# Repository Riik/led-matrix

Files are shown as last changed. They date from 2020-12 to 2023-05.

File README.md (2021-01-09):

# rpi-led-matrix
Python / C control for a LED matrix

# Goal
Create the software for a hardware project which can drive a LED matrix with a extendable number of rows and columns

# Hardware
To drive the rows, the MIC2981 driver IC is used. It can source up to 500mA per pin, which mean 25 columns @ 20mA / column.
To sink the columns, the TPIC6C595 is used. I needs to be able to sink one column (20mA) per pin, so for an 8 bit shift register the total IC must be able to sink 8*20mA. The TPIC6C595 is able to sink up to 100mA per pin.
The rows should multiplexed, i.e. they should not be one at the same time.

# Software
Suitable candidates:
  - PIGpio Python library using DMA control http://abyz.me.uk/rpi/pigpio/
  - Directly talking to SPI hardware in C using IOCTL

# Notes to selfs
  - If multiple rows are active, current is split / LEDS are in parallel with respect to the sinking column.
  - We probably need a resistor per sink / column

# On the subject of the LED matrix 3D model
For this model, we use two programs: OpenSCAD and FreeCAD. OpenSCAD is used to program the model. To make the model readable for KiCad:
1. Open FreeCAD
2. Select View->Workbench->OpenSCAD
3. Open the *.scad file (File->Open)
4. In Combo View->Model->Labels & Attributes->2088BS select union
5. Go to File->Export
6. Export the model as a STEP with colors (*.step *.stp)

# Selected components
 - 100 Ohm 1206 [3216 Metric]: Vishay CRCW1206100RFKEA (https://nl.farnell.com/vishay/crcw1206100rfkea/res-100r-1-0-25w-1206-thick-film/dp/1469977,
 - 10 kOhm 1206 [3216 Metric]: Vishay CRCW120610K0FKEA (https://nl.farnell.com/vishay/crcw120610k0fkea/res-10k-1-0-25w-1206-thick-film/dp/1469970RL,
 - 100 nF (0.1 uF) 1206 [3216 Metric] capacitor: Vishay VJ1206Y104KXQCW1BC (https://nl.farnell.com/vishay/vj1206y104kxqcw1bc/cap-0-1-f-10v-10-x7r-1206/dp/2896644RL,
 - Pin header male: https://nl.farnell.com/multicomp/mc34753/header-1-row-r-angle-8way/dp/1593431?ost=mc34753,
 - Pin header female: https://nl.farnell.com/samtec/ssw-108-02-g-s-ra/receptacle-2-54mm-r-a-single-8way/dp/1668368,

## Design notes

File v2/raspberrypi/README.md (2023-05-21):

This project is able to drive the v2 LED matrix from a raspberry pi 3/4.

# General info
## Configuring the raspberry pi
### SPI
We can configure the SPI very bare-bones, we do not need the MISO line and 1 cs is enough.
Therefore, add the following to `/boot/config`:
```
dtoverlay=spi0-1cs,no_miso
```
If you want to be able to use the spi device as a non-root user, you should create an `spiuser` group:
```
groupadd spiuser
```
Next, create the file `/etc/udev/rules.d/50-spi.rules` with the following content:
```
SUBSYSTEM=="spidev", GROUP="spiuser", MODE="0660"
```
And add your own user to the `spiuser` group:
```
usermod -a -G spiuser <user>
```
You need to log out and log in for the usermod command to take effect.
## Connection
The silkscreen for the male side contains an error, the silkscreen for the female side is correct. You want to connect the female side to the Raspberry Pi. Following [This image](https://www.raspberrypi.com/documentation/computers/images/GPIO-Pinout-Diagram-2.png) we get:
- `Vcc` <--> `5v`
- `GND` <--> `GND`
- `Load` <--> `24` (CE0)
- `CLK` <--> `23` (SCLK)
- `D_in` <--> `19` (MOSI)
- `D_fwd` `N.C.` (d_fwd needs to be connected to another LED matrix)

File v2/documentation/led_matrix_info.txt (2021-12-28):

Led Matrix 8x8 with 3.75 mm pitch between the LED's. LED color is red.

Specifications:

    16 pins connections
    Dimensions: 37.6x37.6mm
    Input voltage: 1.96-2.0 V
    Current:  20 mA

Pinout is indicated in the product images.

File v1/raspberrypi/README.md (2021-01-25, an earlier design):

# On the subject of permissions
To use this software, you need interaction with both gpio and spi. The default permissions for the relevant
devices is root-only, so that you would need to use sudo to run. This is not fun. To fix this, one can create two files:
`/etc/udev/rules.d/50-spi.rules`
```
SUBSYSTEM=="spidev", GROUP="spiuser", MODE="0660"
```
`/etc/udev/rules.d/90-gpio.rules`
```
SUBSYSTEM=="gpio", GROUP="gpiouser", MODE="0660"
```
After udev has been reloaded, the GPIO and SPI devices will be available for users in the groups gpiouser and spiuser.
So add yourself to these groups.

# On the subject of GPIOD
GPIOD is used to control pins directly. The disadvantage of this approach is that, in order to cross-compile, you need the library.
One way to achieve this is to download [the source](https://git.kernel.org/pub/scm/libs/libgpiod/libgpiod.git), run `./autogen.sh --enable-tools=no --prefix=/tmp/libgpiod --host=arm-linux-gnueabihf`, then run `make install` and finally copy `/tmp/libgpiod` to here.

# On the subject of SPI
To control the LED matrix, we use an SPI to transmit data across.
For our purposes, SPI0 is chosen. This means that SPI0 should be enabled, so that `dtoverlay=spi0-1cs` must be added to `/boot/config.txt`.
See also the [raspberry pi documentation](https://www.raspberrypi.org/documentation/hardware/raspberrypi/spi/README.md).

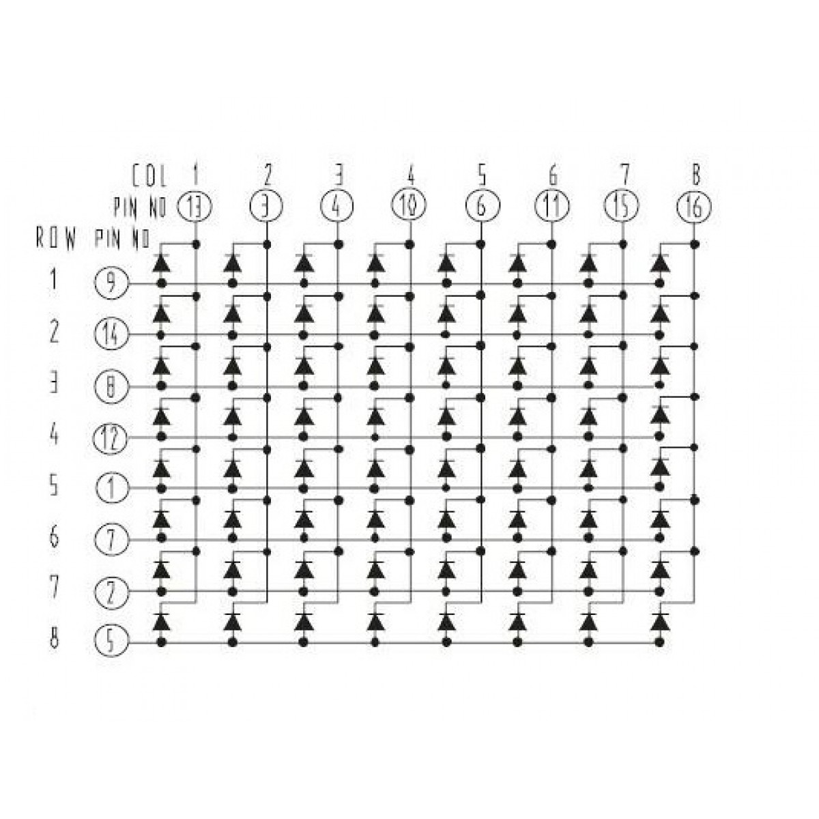
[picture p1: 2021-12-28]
v2/documentation/led_matrix_pinout.jpg

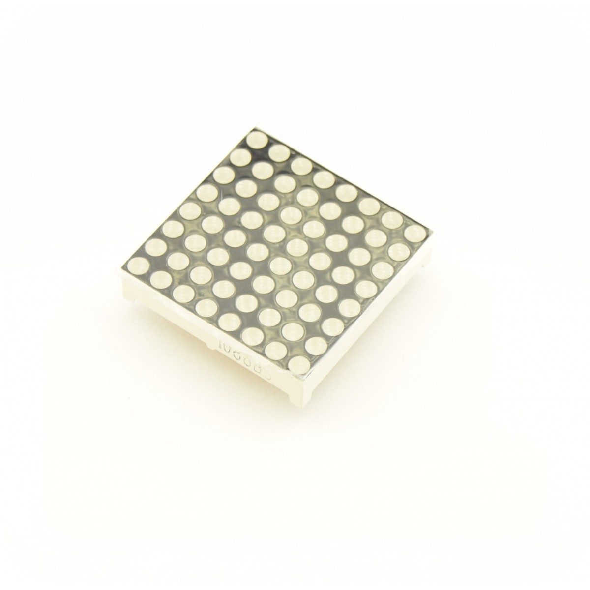
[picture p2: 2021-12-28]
v2/documentation/led_matrix_photo.JPG

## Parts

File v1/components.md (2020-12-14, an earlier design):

CD74HCT4051E, analog 1:8 mux/demux
TPIC6C595N, 8 bit shift register
MIC2981, MIC2981

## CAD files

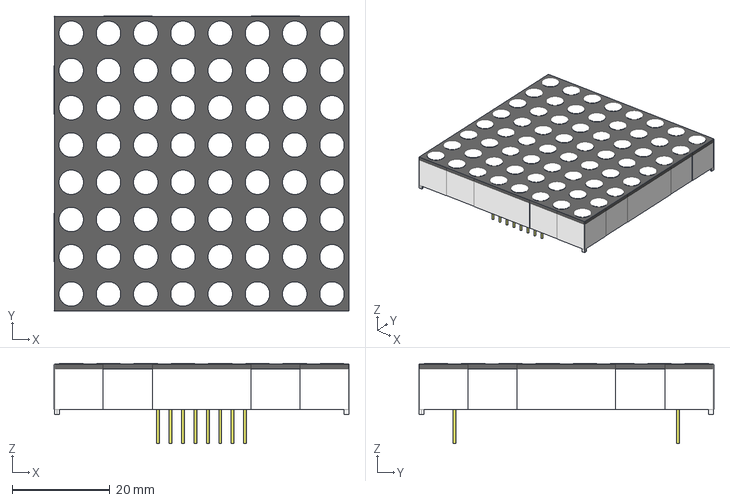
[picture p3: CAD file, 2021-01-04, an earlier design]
v1/kicad/led-matrix/openscad_3d/2088BS.step
60.3 x 60.3 x 16.4 mm

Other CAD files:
v1/kicad/led-matrix/openscad_3d/2088BS.scad

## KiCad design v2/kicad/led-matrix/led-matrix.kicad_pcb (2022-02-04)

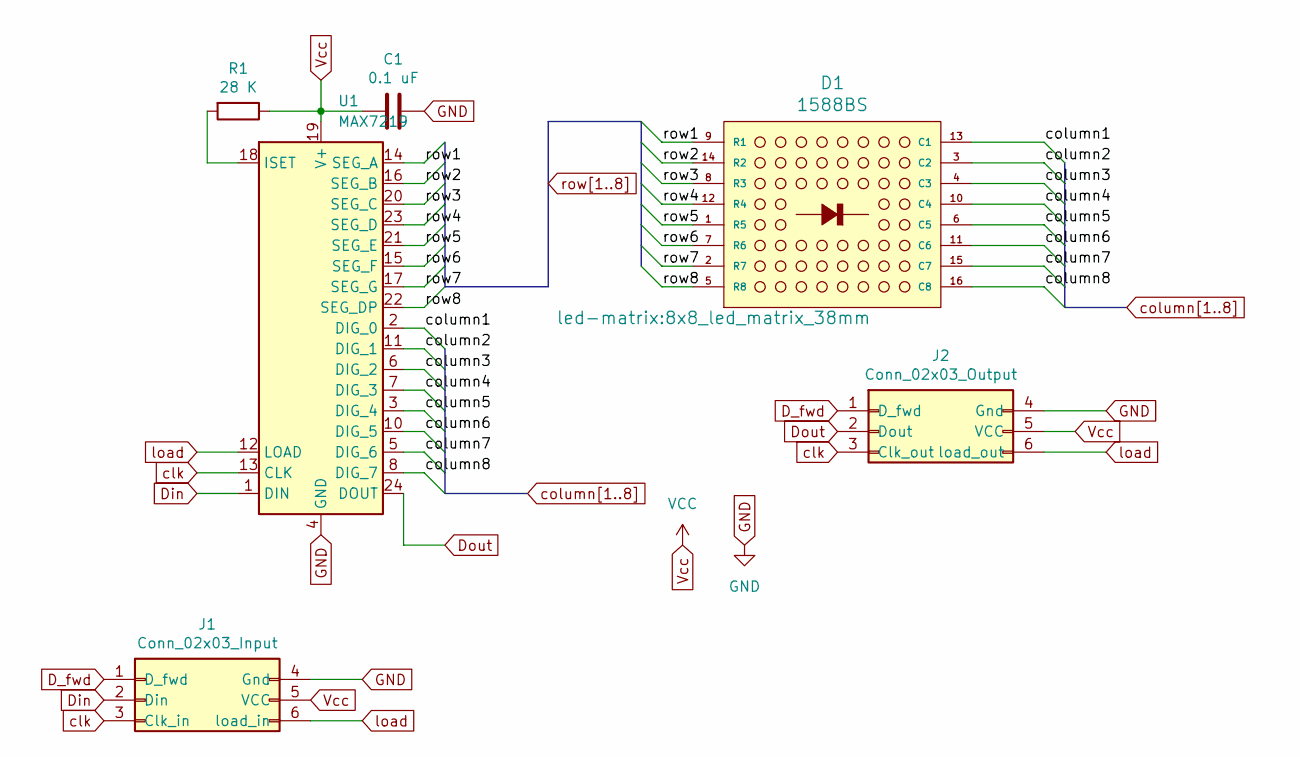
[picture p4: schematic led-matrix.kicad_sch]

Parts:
C1: 0.1 uF; C_1206_3216Metric_Pad1.33x1.80mm_HandSolder
D1: 1588BS; 8x8_led_matrix_38mm
J1: Conn_02x03_Input; PinSocket_2x03_P2.54mm_Horizontal
J2: Conn_02x03_Output; PinHeader_2x03_P2.54mm_Horizontal
R1: 28 K; R_1206_3216Metric_Pad1.30x1.75mm_HandSolder
U1: MAX7219; HandSolder.SOIC-24W_7.5x15.4mm_P1.27mm

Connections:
D_fwd: J1.1 (D_fwd), J2.1 (D_fwd)
Din: J1.2 (Din), U1.1 (DIN)
Dout: J2.2 (Dout), U1.24 (DOUT)
GND: C1.1, J1.4 (Gnd), J2.4 (Gnd), U1.4 (GND), U1.9 (GND)
unnamed: R1.2, U1.18 (ISET)
Vcc: C1.2, J1.5 (VCC), J2.5 (VCC), R1.1, U1.19 (V+)
clk: J1.3 (Clk_in), J2.3 (Clk_out), U1.13 (CLK)
column1: D1.13 (C1), U1.2 (DIG_0)
column2: D1.3 (C2), U1.11 (DIG_1)
column3: D1.4 (C3), U1.6 (DIG_2)
column4: D1.10 (C4), U1.7 (DIG_3)
column5: D1.6 (C5), U1.3 (DIG_4)
column6: D1.11 (C6), U1.10 (DIG_5)
column7: D1.15 (C7), U1.5 (DIG_6)
column8: D1.16 (C8), U1.8 (DIG_7)
load: J1.6 (load_in), J2.6 (load_out), U1.12 (LOAD)
row1: D1.9 (R1), U1.14 (SEG_A)
row2: D1.14 (R2), U1.16 (SEG_B)
row3: D1.8 (R3), U1.20 (SEG_C)
row4: D1.12 (R4), U1.23 (SEG_D)
row5: D1.1 (R5), U1.21 (SEG_E)
row6: D1.7 (R6), U1.15 (SEG_F)
row7: D1.2 (R7), U1.17 (SEG_G)
row8: D1.5 (R8), U1.22 (SEG_DP)

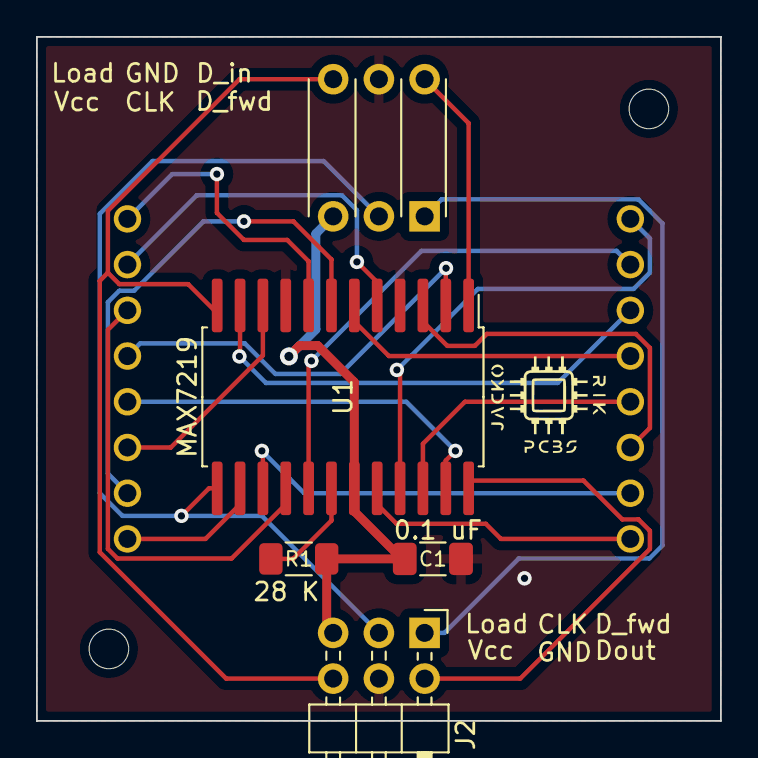
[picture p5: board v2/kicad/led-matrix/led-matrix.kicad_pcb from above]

Board: 2 copper layers, 38.0 x 38.0 mm, 6 parts (1 on the bottom side), 24 nets.

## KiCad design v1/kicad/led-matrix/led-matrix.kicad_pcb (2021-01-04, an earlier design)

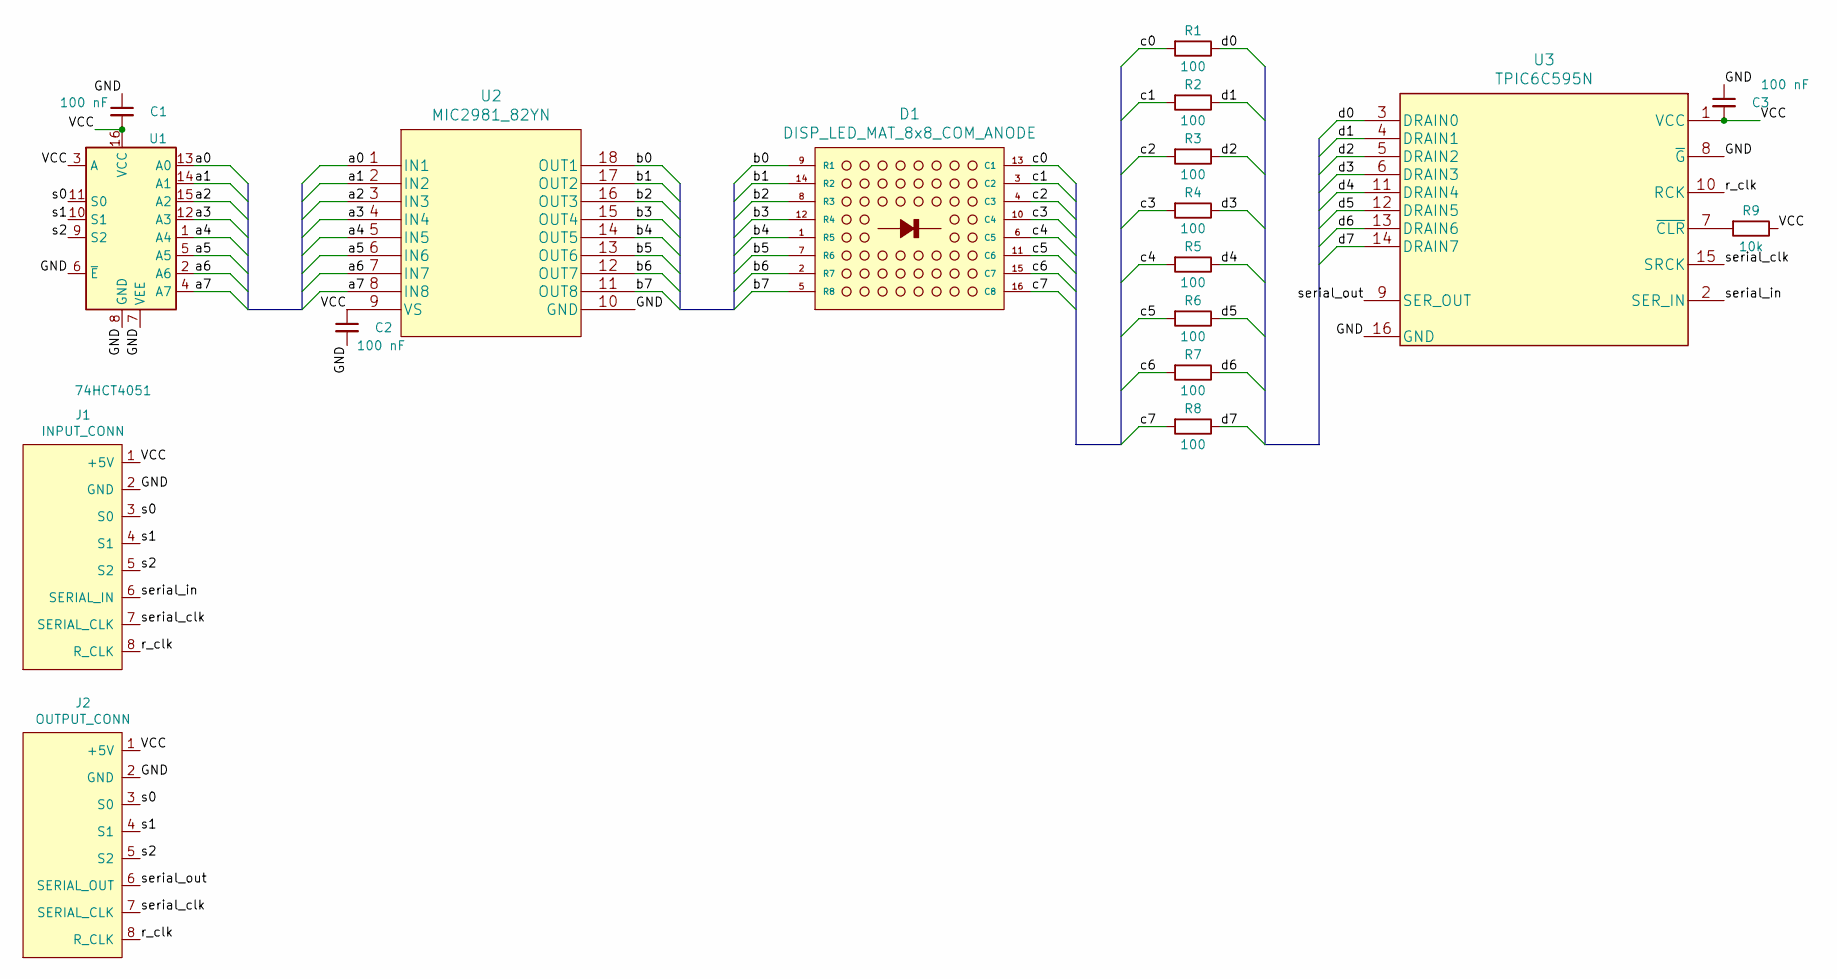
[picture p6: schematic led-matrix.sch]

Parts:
C1, C2, C3: 100 nF; C_1206_3216Metric_Pad1.33x1.80mm_HandSolder
D1: DISP_LED_MAT_8x8_COM_ANODE; LED_8x8_7.62MM_60.2x60.2MM
J1: INPUT_CONN; PinSocket_1x08_P2.54mm_Horizontal
J2: OUTPUT_CONN; PinHeader_1x08_P2.54mm_Horizontal
R1, R2, R3, R4, R5, R6, R7, R8: 100; R_1206_3216Metric_Pad1.30x1.75mm_HandSolder
R9: 10k; R_1206_3216Metric_Pad1.30x1.75mm_HandSolder
U1: 74HCT4051; DIP-16_W7.62mm
U2: MIC2981_82YN; DIP-18_W7.62mm
U3: TPIC6C595N; DIP-16_W7.62mm

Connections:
/GND: C1.1, C2.2, C3.1, J1.2 (GND), J2.2 (GND), U1.6 (~E), U1.7 (VEE), U1.8 (GND), U2.10 (GND), U3.8 (~G), U3.16 (GND)
/VCC: C1.2, C2.1, C3.2, J1.1 (+5V), J2.1 (+5V), R9.1, U1.3 (A), U1.16 (VCC), U2.9 (VS), U3.1 (VCC)
/a0: U1.13 (A0), U2.1 (IN1)
/a1: U1.14 (A1), U2.2 (IN2)
/a2: U1.15 (A2), U2.3 (IN3)
/a3: U1.12 (A3), U2.4 (IN4)
/a4: U1.1 (A4), U2.5 (IN5)
/a5: U1.5 (A5), U2.6 (IN6)
/a6: U1.2 (A6), U2.7 (IN7)
/a7: U1.4 (A7), U2.8 (IN8)
/b0: D1.9 (R1), U2.18 (OUT1)
/b1: D1.14 (R2), U2.17 (OUT2)
/b2: D1.8 (R3), U2.16 (OUT3)
/b3: D1.12 (R4), U2.15 (OUT4)
/b4: D1.1 (R5), U2.14 (OUT5)
/b5: D1.7 (R6), U2.13 (OUT6)
/b6: D1.2 (R7), U2.12 (OUT7)
/b7: D1.5 (R8), U2.11 (OUT8)
/c0: D1.13 (C1), R1.2
/c1: D1.3 (C2), R2.2
/c2: D1.4 (C3), R3.2
/c3: D1.10 (C4), R4.2
/c4: D1.6 (C5), R5.2
/c5: D1.11 (C6), R6.2
/c6: D1.15 (C7), R7.2
/c7: D1.16 (C8), R8.2
/d0: R1.1, U3.3 (DRAIN0)
/d1: R2.1, U3.4 (DRAIN1)
/d2: R3.1, U3.5 (DRAIN2)
/d3: R4.1, U3.6 (DRAIN3)
/d4: R5.1, U3.11 (DRAIN4)
/d5: R6.1, U3.12 (DRAIN5)
/d6: R7.1, U3.13 (DRAIN6)
/d7: R8.1, U3.14 (DRAIN7)
/r_clk: J1.8 (R_CLK), J2.8 (R_CLK), U3.10 (RCK)
/s0: J1.3 (S0), J2.3 (S0), U1.11 (S0)
/s1: J1.4 (S1), J2.4 (S1), U1.10 (S1)
/s2: J1.5 (S2), J2.5 (S2), U1.9 (S2)
/serial_clk: J1.7 (SERIAL_CLK), J2.7 (SERIAL_CLK), U3.15 (SRCK)
/serial_in: J1.6 (SERIAL_IN), U3.2 (SER_IN)
/serial_out: J2.6 (SERIAL_OUT), U3.9 (SER_OUT)
unnamed: R9.2, U3.7 (~CLR)

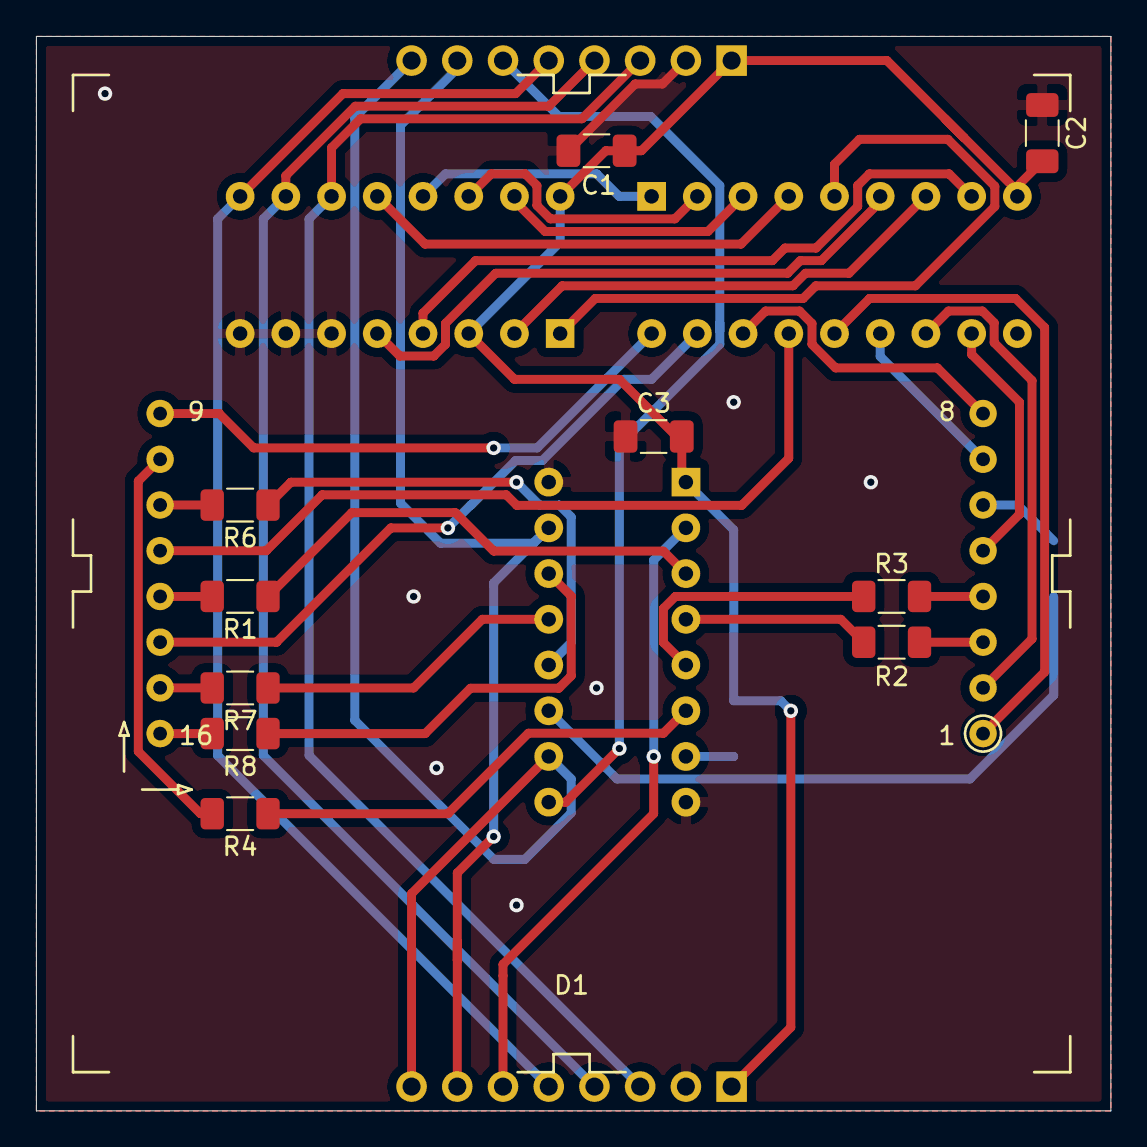
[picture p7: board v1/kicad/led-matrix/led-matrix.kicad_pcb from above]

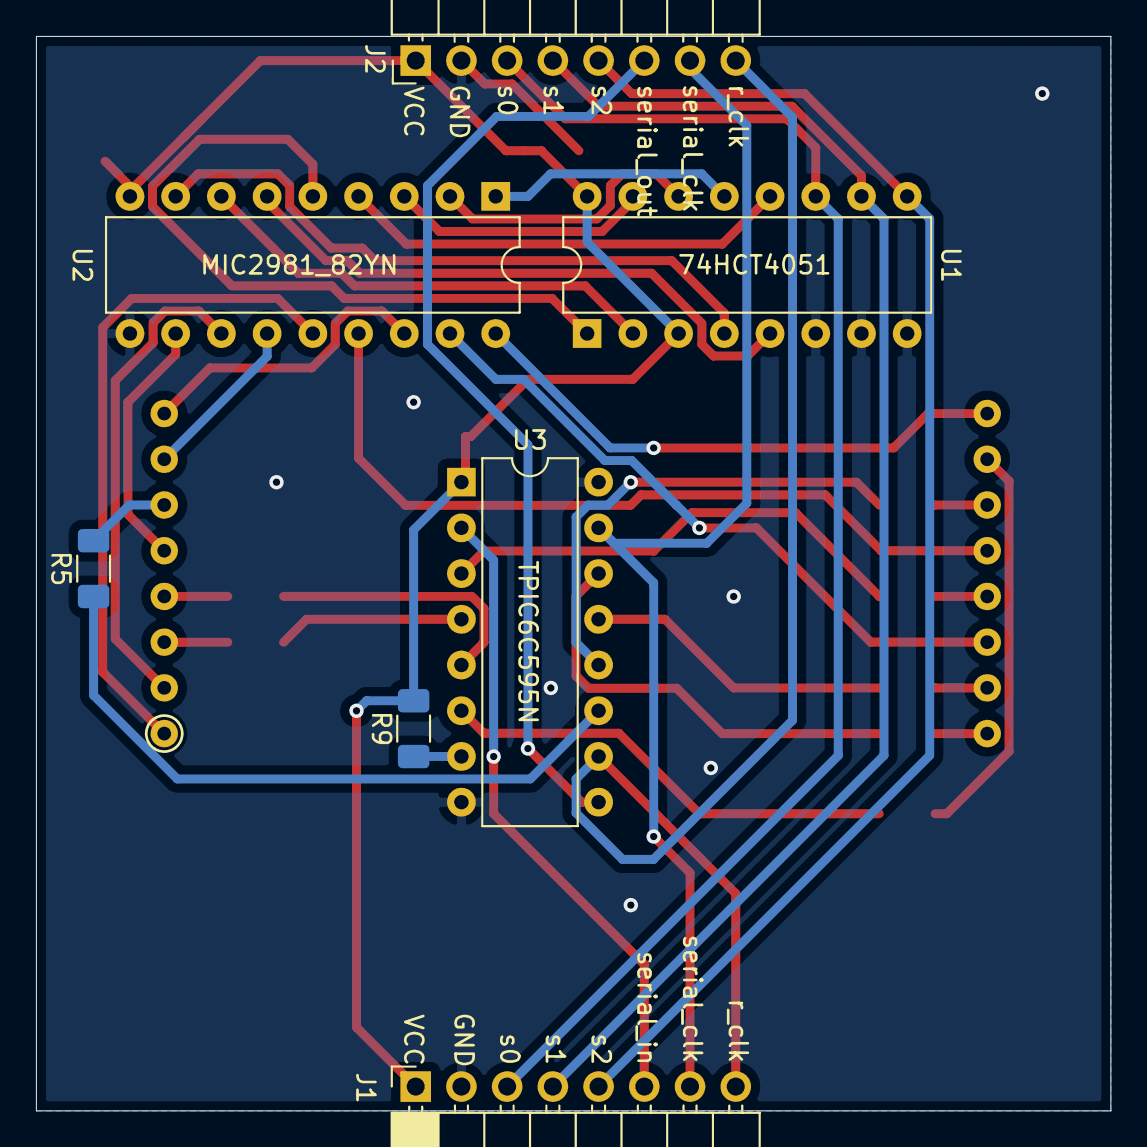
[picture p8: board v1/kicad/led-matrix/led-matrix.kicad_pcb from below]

Board: 2 copper layers, 59.7 x 59.7 mm, 18 parts (7 on the bottom side), 42 nets.

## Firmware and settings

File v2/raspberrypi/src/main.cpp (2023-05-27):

#include <atomic>
#include <csignal>
#include <vector>
#include <chrono>
#include <stdexcept>
#include <iostream>
#include <memory>

#include "matrixScreen.hpp"
#include "matrixDriver.hpp"
#include "matrixDriverSpi.hpp"
#include "matrixDriverNcurses.hpp"
#include "frameLimiter.hpp"
#include "argumentParser.hpp"
#include "textScroller.hpp"
#include "diceGenerator.hpp"

const std::string spidev = "/dev/spidev0.0";
static std::atomic_bool halt = false;

static void sigintHandler(int signum)
{
    halt = true;
}

int main(int argc, char * const argv[]) {
    signal(SIGINT, sigintHandler);

    ParsedArguments pArgs;
    try {
        pArgs = parseArguments(argc, argv);
    } catch (const std::invalid_argument& e) {
        std::cerr << e.what() << std::endl;
        return EXIT_FAILURE;
    }

    MatrixScreen referenceScreen(pArgs.ledMatrixWidth, pArgs.ledMatrixHeight);
    FrameLimiter frameLimiter(pArgs.maxFramesPerSecond);
    std::unique_ptr<MatrixDriver> matrixDriver;
#if !defined(__APPLE__)
    if (pArgs.matrixDriver == SelectedMatrixDriver::spi) {
        matrixDriver = std::make_unique<MatrixDriverSpi>(spidev, referenceScreen, pArgs.brightness);
    } else {
#endif //!defined(__APPLE__)
        matrixDriver = std::make_unique<MatrixDriverNcurses>();
#if !defined(__APPLE__)
    }
#endif //!defined(__APPLE__)
    std::unique_ptr<SubProgram> subProgram;
    if (pArgs.subProgram == SelectedSubProgram::diceGenerator) {
        subProgram = std::make_unique<DiceGenerator>(referenceScreen, pArgs);
    } else {
        subProgram = std::make_unique<TextScroller>(referenceScreen, pArgs);
    }
    while(!halt) {
        matrixDriver->setScreen(subProgram->getScreen());
        frameLimiter.waitForNextFrame();
    }
    return EXIT_SUCCESS;
}

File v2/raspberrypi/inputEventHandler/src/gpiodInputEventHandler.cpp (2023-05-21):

#if !defined(__APPLE__)
#include <iostream>
#include <system_error>
#include <cassert>

#include "gpiodInputEventHandler.hpp"

#include <sys/time.h>

#define BUTTON_PIN 5


GpiodInputEventHandler::GpiodInputEventHandler()
{
    this->chip = gpiod_chip_open("/dev/gpiochip0");
    if(!this->chip) perror("gpiod_chip_open");

    errno = 0;
    this->line = gpiod_chip_get_line(chip, BUTTON_PIN);
    int ret = gpiod_line_request_input(line, "");
    assert(ret == 0);
    int wiee = gpiod_line_set_flags(this->line, GPIOD_LINE_REQUEST_FLAG_BIAS_DISABLE);
    assert(wiee == 0);
    gpiod_line_release(this->line);
    this->line = gpiod_chip_get_line(chip, BUTTON_PIN);

    int err = gpiod_line_request_rising_edge_events(this->line, "rising edge example");
    if(err) perror("gpiod_line_request_bulk_rising_edge_events");
}

GpiodInputEventHandler::~GpiodInputEventHandler(){
    gpiod_line_release(this->line);
    gpiod_chip_close(this->chip);
}

void GpiodInputEventHandler::flushWaitingEvents() {
    gpiod_line_event event;
    while(this->eventWaiting()) {
        gpiod_line_event_read(this->line, &event);
    }
}

bool GpiodInputEventHandler::eventWaiting() {
    static struct timespec timeout = {0};
    int ret = gpiod_line_event_wait(this->line, &timeout);
    if (ret == -1) perror("gpiod_line_event_wait");
    return ret == 1;
}

#endif //!defined(__APPLE)

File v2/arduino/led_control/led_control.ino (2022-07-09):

#include <SPI.h>
#include "font.cpp"
#include <avr/eeprom.h>

#define LOAD  8  // can be changed
#define CLK   13 // fixed by hardware SPI 
#define DATA  11 // fixed by hardware SPI

#define ADDR_INTENSITY  0x0A
#define ADDR_SCAN_LIMIT 0x0B
#define ADDR_SHUTDOWN   0x0C
#define ADDR_TESTMODE   0x0F

#define N_PANELS 8
#define BUFFER_LEN (N_PANELS+1)*8

#define TEXT_BUFF_SIZE 80

#define SPI_SPEED 10000

uint8_t frame_buffer[BUFFER_LEN];
SPISettings spiSettings(SPI_SPEED, MSBFIRST, SPI_MODE0);

char message_receive_buff[TEXT_BUFF_SIZE];
char message_display_buff[TEXT_BUFF_SIZE] = "Hello world!";
uint8_t input_char_count = 0;
uint8_t message_size = 15;
bool string_complete = false; 

void setRegister(uint8_t address, uint8_t value) {    
  digitalWrite(LOAD, LOW);
  for(uint8_t n = 0; n < N_PANELS; n++){
    SPI.transfer(address);
    SPI.transfer(value);
  }
  digitalWrite(LOAD, HIGH);
  delay(1);
}

void serialEvent() {
  if(input_char_count >= TEXT_BUFF_SIZE){
    string_complete = true;
    return;
  }
  while (Serial.available()) {
    input_char_count++;
    char in_char = (char)Serial.read();
    if (in_char == '\n') {
      string_complete = true;
      return;
    }
    message_receive_buff[input_char_count] = in_char;
  }
}

void sendBuffer() {
    for (uint8_t col = 0; col < 8; col++) {
      digitalWrite(LOAD, LOW);
      for(uint8_t n = 0; n < N_PANELS; n++){
        SPI.transfer(col+1);
        SPI.transfer(frame_buffer[col + (N_PANELS-1-n)*8]);
      }
      digitalWrite(LOAD, HIGH);
      delay(1);
    }
}

void moveData(){
  memmove(frame_buffer,frame_buffer+1, BUFFER_LEN-1);
}

void loadData(uint8_t char_idx){
  const uint8_t* offset = font+char_idx*8;
  memcpy_P(frame_buffer, offset, (size_t) BUFFER_LEN);
}

void loadNewCharacter(uint8_t char_idx){
  const uint8_t* offset = font+char_idx*8;
  memcpy_P(frame_buffer+N_PANELS*8, offset, (size_t) 8);
}

void setup() {
  pinMode(LOAD, OUTPUT);
  pinMode(CLK, OUTPUT);
  pinMode(DATA, OUTPUT);

  SPI.begin();
  SPI.beginTransaction(spiSettings);

  setRegister(ADDR_TESTMODE, 0x00);
  setRegister(ADDR_INTENSITY, 0x01);
  setRegister(ADDR_SHUTDOWN, 0x01);
//  setRegister(ADDR_SCAN_LIMIT, 0x07);
  setRegister(ADDR_SCAN_LIMIT, 0x07);
  
  Serial.begin(115200);
  Serial.println("hi");

}

void loop() {
  for(uint8_t i = 0; i < message_size; i++){
    if(string_complete){
      memcpy(message_display_buff, message_receive_buff, TEXT_BUFF_SIZE);
      message_size = input_char_count;
      input_char_count = 0;
      string_complete = false;
      break;
    }
    loadNewCharacter(message_display_buff[i]);   
    for(uint8_t col = 0; col < 8; col++){
      moveData(); 
      sendBuffer();
      delay(35);
    }
    delay(100);
  }

}

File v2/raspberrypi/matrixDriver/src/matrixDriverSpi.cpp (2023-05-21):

#if !defined(__APPLE__)
#include <system_error>
#include <functional>
#include <sstream>
#include <cassert>

#include <fcntl.h>
#include <unistd.h>
#include <sys/ioctl.h>
#include <linux/spi/spidev.h>

#include "matrixDriverSpi.hpp"

MatrixDriverSpi::MatrixDriverSpi(const std::string &spiDevName, MatrixScreen exampleScreen, uint_fast8_t brightness,
        MatrixDriverSpi::PhysicalConnectionLocation physicalConnectionLocation) :
    screen{std::move(exampleScreen)}, matrixCountWidth{exampleScreen.getMatrixCountWidth()},
    matrixCountHeight{exampleScreen.getMatrixCountHeight()},
    physicalConnectionLocation{physicalConnectionLocation}, newDataAvailable{0}
{
    // All spidev stuff will be done c style, since I cant seem to figure out how to do it c++ style.
    this->spifd = open(spiDevName.c_str(), O_RDWR);
    if (this->spifd < 0) {
        throw std::system_error(errno, std::generic_category(), spiDevName);
    }
    assert(brightness <= 15);

    // Now we need to bring the ledmatrices into a default state.
    const std::size_t matrixCount = this->matrixCountWidth * this->matrixCountHeight;
    std::vector<uint8_t> buf(matrixCount*2, 0);
    struct spi_ioc_transfer tr = {0};
    tr.bits_per_word = 8;
    tr.speed_hz = 10000000;
    tr.len = buf.size();
    tr.tx_buf = (unsigned long)buf.data();

    // First we transmit a shutdown to every matrix
    for (std::size_t i = 0; i < buf.size(); i += 2) {
        buf[i] = 0x0C;
        buf[i+1] = 0x00;
    }

    int ret = ioctl(this->spifd, SPI_IOC_MESSAGE(1), &tr);
    if (ret < 0) {
        close(this->spifd);
        throw std::system_error(errno, std::generic_category(), spiDevName);
    }

    // Disable decode mode
    for (std::size_t i = 0; i < buf.size(); i += 2) {
        buf[i] = 0x09;
        buf[i+1] = 0x00;
    }

    ret = ioctl(this->spifd, SPI_IOC_MESSAGE(1), &tr);
    if (ret < 0) {
        close(this->spifd);
        throw std::system_error(errno, std::generic_category(), spiDevName);
    }

    // Disable test mode
    for (std::size_t i = 0; i < buf.size(); i += 2) {
        buf[i] = 0x0F;
        buf[i+1] = 0x00;
    }

    ret = ioctl(this->spifd, SPI_IOC_MESSAGE(1), &tr);
    if (ret < 0) {
        close(this->spifd);
        throw std::system_error(errno, std::generic_category(), spiDevName);
    }

    // Next, transmit scan all lines to every matrix
    for (std::size_t i = 0; i < buf.size(); i += 2) {
        buf[i] = 0x0B;
        buf[i+1] = 0x07;
    }

    ret = ioctl(this->spifd, SPI_IOC_MESSAGE(1), &tr);
    if (ret < 0) {
        close(this->spifd);
        throw std::system_error(errno, std::generic_category(), spiDevName);
    }

    // Finally, we set brightness on every matrix
    for (std::size_t i = 0; i < buf.size(); i += 2) {
        buf[i] = 0x0A;
        buf[i+1] = static_cast<uint8_t>(brightness);
    }

    ret = ioctl(this->spifd, SPI_IOC_MESSAGE(1), &tr);
    if (ret < 0) {
        close(this->spifd);
        throw std::system_error(errno, std::generic_category(), spiDevName);
    }
    // Create and start the thread
    this->outputWorker = std::jthread(std::bind_front(&MatrixDriverSpi::screenToSpi, this));
}

MatrixDriverSpi::~MatrixDriverSpi()
{
    // We explicitly stop the jthread to stop it from interfering with our ledmatrix shutdown code.
    this->outputWorker.request_stop();
    this->outputWorker.join();

    // Now we need to bring the ledmatrices into a default state.
    const std::size_t matrixCount = this->matrixCountWidth * this->matrixCountHeight;
    std::vector<uint8_t> buf(matrixCount*2, 0);
    struct spi_ioc_transfer tr = {0};
    tr.bits_per_word = 8;
    tr.speed_hz = 10000000;
    tr.len = buf.size();
    tr.tx_buf = (unsigned long)buf.data();

    // Transmit a shutdown to every matrix
    for (std::size_t i = 0; i < buf.size(); i += 2) {
        buf[i] = 0x0C;
        buf[i+1] = 0x00;
    }
    ioctl(this->spifd, SPI_IOC_MESSAGE(1), &tr);

    // Close our filedescriptor
    close(this->spifd);
}

void MatrixDriverSpi::setScreen(MatrixScreen screen)
{
#if defined(DEBUG)
    if (screen.getMatrixCountWidth() != this->screen.getMatrixCountWidth()) {
        std::stringstream ss;
        ss << "Matrix count width is incorrect. Expected: " << this->screen.getMatrixCountWidth() << ", got: " << screen.getMatrixCountWidth();
        throw std::out_of_range(ss.str());
    }

    if (screen.getMatrixCountHeight() != this->screen.getMatrixCountHeight()) {
        std::stringstream ss;
        ss << "Matrix count height is incorrect. Expected: " << this->screen.getMatrixCountHeight() << ", got: " << screen.getMatrixCountHeight();
        throw std::out_of_range(ss.str());
    }
#endif //defined(DEBUG)

    this->screenMutex.lock();
    this->screen = std::move(screen);
    this->screenMutex.unlock();
    this->newDataAvailable.notify();
}
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

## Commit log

2020-11-02 change row and columns in led matrix description
2020-11-16 Add arduino code for animation
2020-11-17 Add sprites and conversion script
    [converted_sprites.tsv]
2020-11-17 Add font image and conversion script
    [font_converted.tsv]
2020-12-01 move KITT_rik.ino to Arduino folder
2020-12-01 Empty eagle project
    [led-matrix.brd, led-matrix.sch]
2020-12-01 Add PCB library files
2020-12-14 Add a kicad test project
    [test.kicad_pcb, test.sch]
2020-12-14 new empty kicad file
    [led-matrix.kicad_pcb, led-matrix.sch]
2020-12-14 Remove all traces of EAGLE
    [led-matrix.brd, led-matrix.sch]
2020-12-14 Add MIC2981 lib file to KiCAD
2020-12-14 Add led matrix library file
    [led-matrix.sch]
2020-12-14 Update schematix
    [led-matrix.sch]
2020-12-16 Remove kicad_test
    [test.kicad_pcb, test.sch]
2020-12-16 KiCad: Add INPUT_CONN
    From Arduino to this board
2020-12-16 KiCad: Add correct TPIC6C595N
2020-12-16 KiCad: Update TPIC6C595N to match rest
2020-12-16 KiCad: Update MIC2981 to match rest
2020-12-16 KiCad: Update schematic
    Now contains main pipeline
    [led-matrix.sch]
2020-12-16 KiCad: Finish labeling as far as possible
    Still need to add an output header
    [led-matrix.sch]
2020-12-16 Finishes schematic
    [led-matrix.sch]
2020-12-17 Add AKNs' footprints and 3d models
2020-12-17 Update schematic, pcb
    [led-matrix.kicad_pcb, led-matrix.sch]
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2020-12-22 Kicad: Schematic: Add capacitors and additional resistor
    [led-matrix.sch]
2020-12-22 Kicad: PCB: Add GND planes
    [led-matrix.kicad_pcb]
2020-12-22 Organized components and placed headers
    [led-matrix.kicad_pcb]
2020-12-28 Add a 3D model of the 2088BS LED matrix
    [2088BS.scad, 2088BS.step]
2020-12-28 Remove unusded models and footprints
2020-12-31 Routing left side and upper ICs
    [led-matrix.kicad_pcb]
2020-12-31 Complete routing and clear up ground planes
    [led-matrix.kicad_pcb]
2021-01-04 Updated 3D model and fixed Edge.Cuts layer
    [led-matrix.kicad_pcb, led-matrix.sch]
2021-01-04 Tweak silk screen
    [led-matrix.kicad_pcb]
2021-01-04 Gerber files for first order
    [led-matrix-B_Cu.gbr, led-matrix-B_Mask.gbr, led-matrix-B_Paste.gbr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]
2021-01-06 KiCad: Schematic: Update footprint for J1 and J2
    [led-matrix.sch]
2021-01-09 Add component information and datasheets
    [led-matrix.sch]
2021-01-13 Makefile compiles and uploads but code doesn't work now
    [arduino_text_disp.ino, main.cpp]
2021-01-23 Update code for new LED matrix and optimize address pin timings
2021-01-25 Add raspberry pi code
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2021-01-25 raspberrypi: Add code opening relevant devices
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2021-01-26 raspberrypi: Makefile: Remove CXXFLAGS
    No C++ here
2021-01-26 raspberrypi: inc/pabort: Include errno
2021-01-26 raspberrypi: Rework matrix driving
    Using a dual buffered approach
    [main.c, matrixDriver.c]
2021-01-26 raspberrypi: Introduce rolling text
2021-01-27 raspberrypi: matrixDriver: We iterate over rows
2021-01-27 raspberrypi: matrixDriver: One spi_ioc_transfer is enough
2021-01-27 raspberrypi: matrixDriver: Use chip select as rck
2021-01-31 raspberrypi: Rename: rows -> colCount
2021-01-31 raspberrypi: main: Rework text length calculation
    [main.c]
2021-01-31 raspberrypi: main: atomic_bool halt is static
2021-01-31 raspberrypi: main: Clear LED matrix on exit
2021-01-31 raspberrypi: matrixDriver.h: Add explanation
2021-01-31 raspberrypi: matrixDriver: Only load buf before row 0
    Bugfix: The buffer could swap halfway through, which causes tearing.
    This is fixed now.
    [matrixDriver.c]
2021-01-31 raspberrypi: Add brightness percentage
2021-01-31 matrixDriver: Use C11 threads instead of pthreads
2021-02-07 raspberrypi: matrixDriver: Add spiMsgSize var
2021-02-07 raspberrypi: Rework code for multiple led matrices
    [main.c]
2021-03-27 raspberrypi: Makefile: Add -wshadow
2021-03-27 raspberrypi: Makefile: Set some warnings back to warning
2021-03-27 raspberrypi: Introduce a tileRenderer
2021-03-27 raspberrypi: Fix generic amount of LED tiles
    [main.c]
2021-03-27 raspberrypi: Finish tileRenderer for x direction
2021-04-03 raspberrypi: tileRenderer: Remove continue in for loop
    Just start at the correct point instead of continuing until you get
    there.
2021-04-03 raspberrypi: tileRenderer: Fix support for xLen < 8
    [main.c]
2021-04-03 raspberrypi: tileRenderer: Allow merging of multiple objects
2021-04-03 raspberrypi: tileRenderer: Introduce y-axis control
2021-12-28 Move v1 files to archive folder
    [2088BS.scad, 2088BS.step, converted_sprites.tsv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]
2021-12-28 Add led matrix photo
2021-12-28 v2: Introduce kicad project
    [led-matrix.kicad_pcb, led-matrix.sch]
2022-01-08 gitignore: Fix raspberrypi ignores
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2022-01-08 v2: KiCAD: Upgrade to v6
    [led-matrix.kicad_sch, led-matrix.sch]
2022-01-08 v2: KiCAD: Update schematic names, datasheet
    [led-matrix.kicad_sch]
2022-01-08 v2: KiCAD: Add labels vcc, load
    [led-matrix.kicad_sch]
2022-01-08 v2: KiCAD: Finish schematic
    [led-matrix.kicad_sch]
2022-01-15 v2: Introduce led_matrix footprint, add footprints to schematic
    [led-matrix.kicad_sch]
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2022-01-27 V2: Update schematic
    [led-matrix.kicad_sch]
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2022-01-28 Correct placement for headers, centred and 2.35 mm from edge
    [led-matrix.kicad_pcb]
2022-02-02 Routing attempt 3
    [led-matrix.kicad_pcb]
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2022-02-04 V2: Make PCB prettier
    [led-matrix.kicad_pcb]
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2022-02-04 Changed footprint to handsoldering and added logo
    [led-matrix.kicad_pcb, led-matrix.kicad_sch]
2022-02-04 Aesthetics updates to PCB
    [led-matrix.kicad_pcb]
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2022-06-05 v2:rpi:FrameLimiter: Fix public
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2022-06-05 v2:rpi:2dgfx: canvas: Introduce clipping space
    Now the canvas scales with the amount of led matrices, instead of
    creating a bigger window to look through.
2022-06-05 v2:rpi:2dgfx: canvas test: Add empty frame, multiple layouts
2022-06-05 v2:rpi:Rename files to prevent future conflicts
    [main.cpp]
2022-07-09 add some game of life code and experiments
    [font_converted.tsv]
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2022-10-17 v2:rpi: Add archflags to linker stage
    This could help in optimizations, such as only including code for the
    specific platform.
2022-10-17 v2:rpi: Disable matrixDriverSpi under APPLE
    The SPI stuff is Linux specific and therefore will not work under Apple.
    Make sure it does not get compiled.
    [matrixDriverSpi.cpp]
2023-04-15 v2:rpi: Select matrix driver via args
    Unless APPLE, unfortunately :(
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
